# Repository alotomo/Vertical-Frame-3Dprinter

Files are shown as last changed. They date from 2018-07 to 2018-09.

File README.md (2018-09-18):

# Vertical-Frame-3Dprinter
This file is include the 3D CAD, firmware ,Simplify3D fff .
video : https://vimeo.com/286761862

3D CAD data is .IGS file . for solidworks and Fusion360 and more .
Firmware is based marlin-firmware and customized.
.FFF  for Simplify3D

物品リスト is BOM file

FABOOL laser Mini を元に改造したマシンです
https://github.com/smartDIYs
https://www.thingiverse.com/smartDIYs/designs

組み立て参考サイト: https://www.smartdiys.com/manual/fabool-laser-mini/
部品参考サイト: https://www.smartdiys.com/manual/fabool-laser-mini-service-parts/

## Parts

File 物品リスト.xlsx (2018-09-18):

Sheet: 部品リスト
 | マシン本体
 | FABOOL 基本キットから仕様している物 | https://www.smartdiys.com/manual/fabool-laser-mini-service-parts/
 | 品名 | 型番・ファイル名 | 個数 | 備考 | URL
 | プーリー固定用パーツ | FLM_idler pulley plate | 2
 | モーター固定用パーツY軸 | FLM_motor mount plate y-axis | 2
 | モーター固定用パーツX軸 | FLM_motor mount plate x-axis | 1
 | レーザー取り付けプレート | FLM_mini v plate_C | 1 | mini v plate_C
 | ブラケット |  | 4
 | タイミングプーリー |  | 3 | GT2 30歯
 | ステッピングモーター | NEMA17 | 3
 | smooth idler pulleyユニット |  | 3
 | 偏心スペーサー |  | 9
 | ブラケット |  | 4
 | M5 Tナット（先入れ） |  | 16 | 10
 | FABOOL １ｍ拡張キットから仕様している物
 | 20mm角アルミフレーム | V-slot 1170mm | 4
 | 20mm40mmアルミフレーム | V-slot 1210mm | 1
 | アルミフレーム固定用L | FLM_mini v plate_L_2040_1m | 1
 | アルミフレーム固定用R | FLM_mini v plate_R_2040_1m | 1
 | X軸タイミングベルト |  | 1 | GT2 長さ2m以上
 | Y軸タイミングベルト |  | 2 | GT2 長さ2m以上
 | 拡張キット組み立てURL
 | https://www.smartdiys.com/manual/category/fabool-extension-frame/
 | キットに含まれず別途用意する物品
 | 吸盤 | バキュームリフター | 8 | Amazon | http://amzn.asia/d/f4iNQeI (https://e3d-online.com/titan-extruder)
 | 吸盤固定用パーツ | kyuban_0521 V21 | 8 | ３Dプリント品
 | X軸用リミットスイッチ固定用パーツ | Mech_switch_cover | 1 | レーザーカット品
 | Y軸用リミットスイッチ固定用パーツ | Mech_switch_cover_Y | 1 | レーザーカット品
 | ベルトテンション調整機構1 | y_belt_base | 1 | ３Dプリント品
 | ベルトテンション調整機構2 | y_belt_tens | 1 | ３Dプリント品
 | ベアリング | （外形19mm,内径6mm) | 3 | 千石電商など | https://www.sengoku.co.jp/mod/sgk_cart/detail.php?code=EEHD-4JWW
 | ベアリングカバー（厚紙1㎜ or アクリル1mm) | bearing-cover | 3 | レーザーカット品
 | コントロールボードケース１ | MB_Case2 | 1 | ３Dプリント品
 | コントロールボードケース2 | TRIGORILLA_Case_2 | 1 | ３Dプリント品
i | 操作パネルケース1 | LCD_cover | 1 | ３Dプリント品
 | 操作パネルケース2 | LCD_Cover_Bottom | 1 | ３Dプリント品
 | 操作パネルケース3 | LCD_Switch_Bottom | 1 | ３Dプリント品
i | 操作パネルケース固定プレート | LCD_Plate | 1 | レーザーカット品
電子制御部 | コントロールボード | TriGorilla | 1 |  | http://amzn.asia/fg12sFn
 | モータードライバ | A4988 | 1 | (5個セット) | http://amzn.asia/jdB5D4b
 | コントロールパネル | LCD12864 | 1 |  | http://amzn.asia/hCJs8hi
 | 電源用スイッチ |  | 1 | 千石電商 | https://www.sengoku.co.jp/mod/sgk_cart/detail.php?code=EEHD-0GE3
 | 電源用ケーブルAWG16(1.25sq) | 5ｍ程度 |  | オヤイデ電気 | https://oyaide.com/catalog/products/p-2201.html
 | ２．１ｍｍ標準ＤＣプラグ（５Ａ） |  | 1 | 秋月電子 | http://akizukidenshi.com/catalog/g/gC-09311/
 | XT60オスメスコネクタ |  | 1 |  | http://amzn.asia/d/fPNdAga
 | モーター・スイッチケーブル（対数） | MAST-UL2464-24-4P-10 | 1 | 10m | https://jp.misumi-ec.com/vona2/detail/110400411830/?ProductCode=MAST-UL2464-24-8P-10
 | コントロールボード冷却ファン | １２Ｖ３０ｍｍ角 ＤＣファン | 2 | 秋月電子 | http://akizukidenshi.com/catalog/g/gP-02439/
 | JSTコネクタ キット |  |  |  | http://amzn.asia/d/3IZjlXz
 | ジャンプワイヤ |  | 1 |  | http://amzn.asia/d/7e0MaCI
Z機構 ＆ 押出機 | 5mmアクリル | 300mm×500mm | 1
 | 2mmアクリル | 300mm×500mm | 1
 | 小型ステッピングモーター | 28BYJ-48 12Vタイプ | 2 |  | https://ja.aliexpress.com/item/28BYJ-48-Valve-Gear-Stepper-Motor-DC-12V-4-Phase-Step-Motor-Reduction/32554681156.html
 | チューブ継手1.75mm用 | 空気圧継手 PC4-01 | 1 | 1.75mm用 | http://amzn.asia/8W7XnIh
 | フィラメントチューブ1.75mm用 | PTFEチューブ2mm×4mm | 1 | 1.75mm用 | http://amzn.asia/6lfQt3v
 | チューブ継手3.00mm用 | 空気圧継手 PC4-01 | 1 | 3mm用 | http://amzn.asia/aPkcgBb
 | フィラメントチューブ3.00mm用 | PTFEチューブ4mm×6mm | 1 | 3mm用 | http://amzn.asia/8XIWpak
 | 円形インサートナット | 3mm× 5mm× 5mm |  |  | http://amzn.asia/hwDNwGC
 | ベアリング | 8mmベアリング
 | フィラメント押出機 | titan Extruder |  | TYPE１ | https://e3d-online.com/titan-extruder
 |  |  |  |  | http://amzn.asia/ihe9tIm
 |  |  |  |  | https://ja.aliexpress.com/item/BIGTREETECH-Titan-Extruder-Fully-Kits-for-Titan-Extruder-for-1-75mm-Nema-17-Stepper-Motor-V6/32789942768.html
 | 追加パーツ
 | 六角穴付きボルトセット |  |  |  | http://amzn.asia/d/eHFy7Kc
 | 六角穴付組み込みボルトセット |  |  |  | http://amzn.asia/d/cQYwSAI
 | M3/4/5 六角穴付きボルト セット |  |  |  | http://amzn.asia/d/aryfefD
 | M3後入れナット |  | 1 | AliExpress | https://ja.aliexpress.com/store/product/50-m3-m4-m5-t-2020/3108017_32834673316.html
 | M4後入れナット |  | 1 | AliExpress | https://ja.aliexpress.com/store/product/50-m3-m4-m5-t-2020/3108017_32834673316.html
 | M5後入れナット |  | 1 | AliExpress | https://ja.aliexpress.com/store/product/50-m3-m4-m5-t-2020/3108017_32834673316.html
 | マシン剛性強化パーツ
 | 押出厚型ブラケット | HBLTS5 |  | MISUMI | https://jp.misumi-ec.com/vona2/detail/110300438050/?HissuCode=HBLTS5
 | 検討・改良用パーツ
 | 3フィラメント混合ノズル | Diamond Extruder |  | 今回未使用 | https://ja.aliexpress.com/item/Diamond-3D-Printer-Extruder-Hotend-3D-V6-heatsink-3-IN-1-OUT-Multi-Nozzle-KOSSEL-full/32779018878.html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

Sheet: Fabool公式
参考URL
https://www.smartdiys.com/manual/fabool-laser-mini-service-parts/
FABOOL Laser Mini マニュアル
保守部品
保守部品 価格表
品名 | 販売単位 | 価格(税込) | 備考
1.6Wレーザーユニット（レーザー基板付属） | 1 | 16,740円
3.5Wレーザーユニット（レーザー基板付属） | 1 | 36,504円
コントロール基板 | 1 | 7,980円
V-slot 450mm | 1 | 2,700円
V-slot 410mm | 1 | 2,484円
ブラケット | 4 | 1,728円
タイミングプーリー | 1 | 1,274円 | GT2 30歯
X軸タイミングベルト | 1 | 850円 | GT2 長さ1060m
Y軸タイミングベルト | 1 | 800円 | GT2 長さ1000m
光学ステージ | 1 | 1,760円
光学キャリア | 1 | 1,760円
PCBケース | 1 | 2,700円
mini v plate_C | 1 | 3,240円 | 組立済
mini v plate_L | 1 | 3,110円 | 組立済
mini v plate_R | 1 | 3,780円 | 組立済
idler pulley plate | 1 | 1,620円 | 組立済
ACアダプタ | 1 | 2,160円
ACケーブル | 1 | 518円
USBケーブル | 1 | 864円
ステッピングモーター | 1 | 1,922円
DCファン | 1 | 540円 | PCBケース用
PCBケーブル | 1 | 518円
Laserケーブル | 1 | 1,382円
X-Axisケーブル | 1 | 950円
Y-Axis-Rケーブル | 1 | 518円
Y-Axis-Lケーブル | 1 | 950円
Foot Switchケーブル | 1 | 842円
保護メガネ | 1 | 2,462円
高さ調整用アクリル | 1 | 216円
結束バンド固定具 | 6 | 518円
結束バンド | 25 | 410円
mini v wheelユニット | 1 | 1,058円
smooth idler pulleyユニット | 1 | 1,058円
偏心スペーサー | 3 | 907円
motor mount plate x-axis | 1 | 1,382円
motor mount plate y-axis | 1 | 1,620円
M3×6 六角穴付き皿ボルト | 5 | 410円 | PCBケース用ネジ
M6×8 六角穴付きボルト | 3 | 410円
M5×8 低頭ボルト | 5 | 518円
M5×6 低頭ボルト | 5 | 518円
M4×6 六角穴付きボルト | 1 | 130円
M3×10 六角穴付きボルト | 5 | 410円
M3×6 六角穴付きボルト | 5 | 410円
M3×4 六角穴付きボルト | 5 | 410円
M2×10 六角穴付きボルト | 5 | 410円
M5 Tナット | 5 | 410円
M3後入れナット | 3 | 410円

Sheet: Sheet1
部品データ
レーザーカッター | メーカー | 個数 | 備考 |  | オプション | 代用可
FABOOL Laser Mini 1.6W | SmartDIYs | 1 |  | https://shop.smartdiys.com/products/detail.php?product_id=773
拡張フレームセット(加工エリア1m×1m) | SmartDIYs | 1 |  | https://shop.smartdiys.com/products/detail.php?product_id=779
Z機構改造パーツ
部品・材料 | 部品名・型番 | 個数 | 備考 | 購入参考URL
5mmアクリル
2mmアクリル
小型ステッピングモーター | 28BYJ-48 12Vタイプ |  |  | https://ja.aliexpress.com/item/28BYJ-48-Valve-Gear-Stepper-Motor-DC-12V-4-Phase-Step-Motor-Reduction/32554681156.html
チューブ継手1.75mm用 | 空気圧継手 PC4-01 | 1 | 1.75mm用 | http://amzn.asia/8W7XnIh
フィラメントチューブ1.75mm用 | PTFEチューブ2mm×4mm | 1 | 1.75mm用 | http://amzn.asia/6lfQt3v
チューブ継手3.00mm用 | 空気圧継手 PC4-01 | 1 | 3mm用 | http://amzn.asia/aPkcgBb
フィラメントチューブ3.00mm用 | PTFEチューブ4mm×6mm | 1 | 3mm用 | http://amzn.asia/8XIWpak
円形インサートナット | 3mm× 5mm× 5mm |  |  | http://amzn.asia/hwDNwGC
ベアリング | 8mmベアリング
フィラメント押出機 | titan Extruder |  | TYPE１ | https://e3d-online.com/titan-extruder
 |  |  |  | http://amzn.asia/ihe9tIm
 |  |  |  | https://ja.aliexpress.com/item/BIGTREETECH-Titan-Extruder-Fully-Kits-for-Titan-Extruder-for-1-75mm-Nema-17-Stepper-Motor-V6/32789942768.html
電子制御部
コントロールボード | TriGorilla | 1 |  | http://amzn.asia/fg12sFn
モータードライバ | A4988 | 1 | (5個セット) | http://amzn.asia/jdB5D4b
コントロールパネル | LCD12864 | 1 |  | http://amzn.asia/hCJs8hi
電源用スイッチ |  | 1 | 千石電商 | https://www.sengoku.co.jp/mod/sgk_cart/detail.php?code=EEHD-0GE3 |  | 〇
電源用ケーブルAWG16(1.25sq) | 5ｍ程度 |  | オヤイデ電気 | https://oyaide.com/catalog/products/p-2201.html |  | 〇
２．１ｍｍ標準ＤＣプラグ（５Ａ） |  | 1 | 秋月電子 | http://akizukidenshi.com/catalog/g/gC-09311/ | オプション・電源端子を別途使う場合のみ | 〇
XT60オスメスコネクタ |  | 1 |  | http://amzn.asia/d/fPNdAga |  | 〇
コントロールボード冷却ファン | １２Ｖ３０ｍｍ角 ＤＣファン | 2 | 秋月電子 | http://akizukidenshi.com/catalog/g/gP-02439/ |  | 〇
ジャンプワイヤ |  | 1 |  | http://amzn.asia/d/7e0MaCI |  | 〇
追加パーツ
JSTコネクタ キット |  |  |  | http://amzn.asia/d/3IZjlXz
六角穴付きボルトセット |  |  |  | http://amzn.asia/d/eHFy7Kc
六角穴付組み込みボルトセット |  |  |  | http://amzn.asia/d/cQYwSAI
M3/4/5 六角穴付きボルト セット |  |  |  | http://amzn.asia/d/aryfefD
M3後入れナット |  | 1 | AliExpress | https://ja.aliexpress.com/store/product/50-m3-m4-m5-t-2020/3108017_32834673316.html
M4後入れナット |  | 1 | AliExpress | https://ja.aliexpress.com/store/product/50-m3-m4-m5-t-2020/3108017_32834673316.html
M5後入れナット |  | 1 | AliExpress | https://ja.aliexpress.com/store/product/50-m3-m4-m5-t-2020/3108017_32834673316.html
マシン剛性強化パーツ
押出厚型ブラケット | HBLTS5 |  | MISUMI | https://jp.misumi-ec.com/vona2/detail/110300438050/?HissuCode=HBLTS5
検討・改良用パーツ
3フィラメント混合ノズル | Diamond Extruder |  | 今回未使用 | https://ja.aliexpress.com/item/Diamond-3D-Printer-Extruder-Hotend-3D-V6-heatsink-3-IN-1-OUT-Multi-Nozzle-KOSSEL-full/32779018878.html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

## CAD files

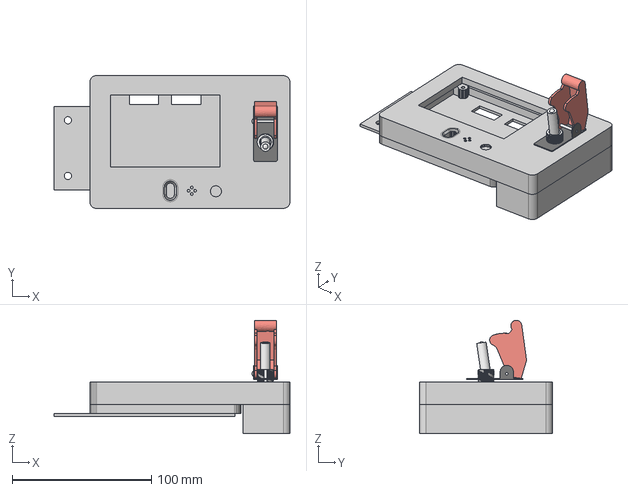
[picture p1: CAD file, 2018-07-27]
controller_case.iges
169.6 x 95.4 x 81.5 mm

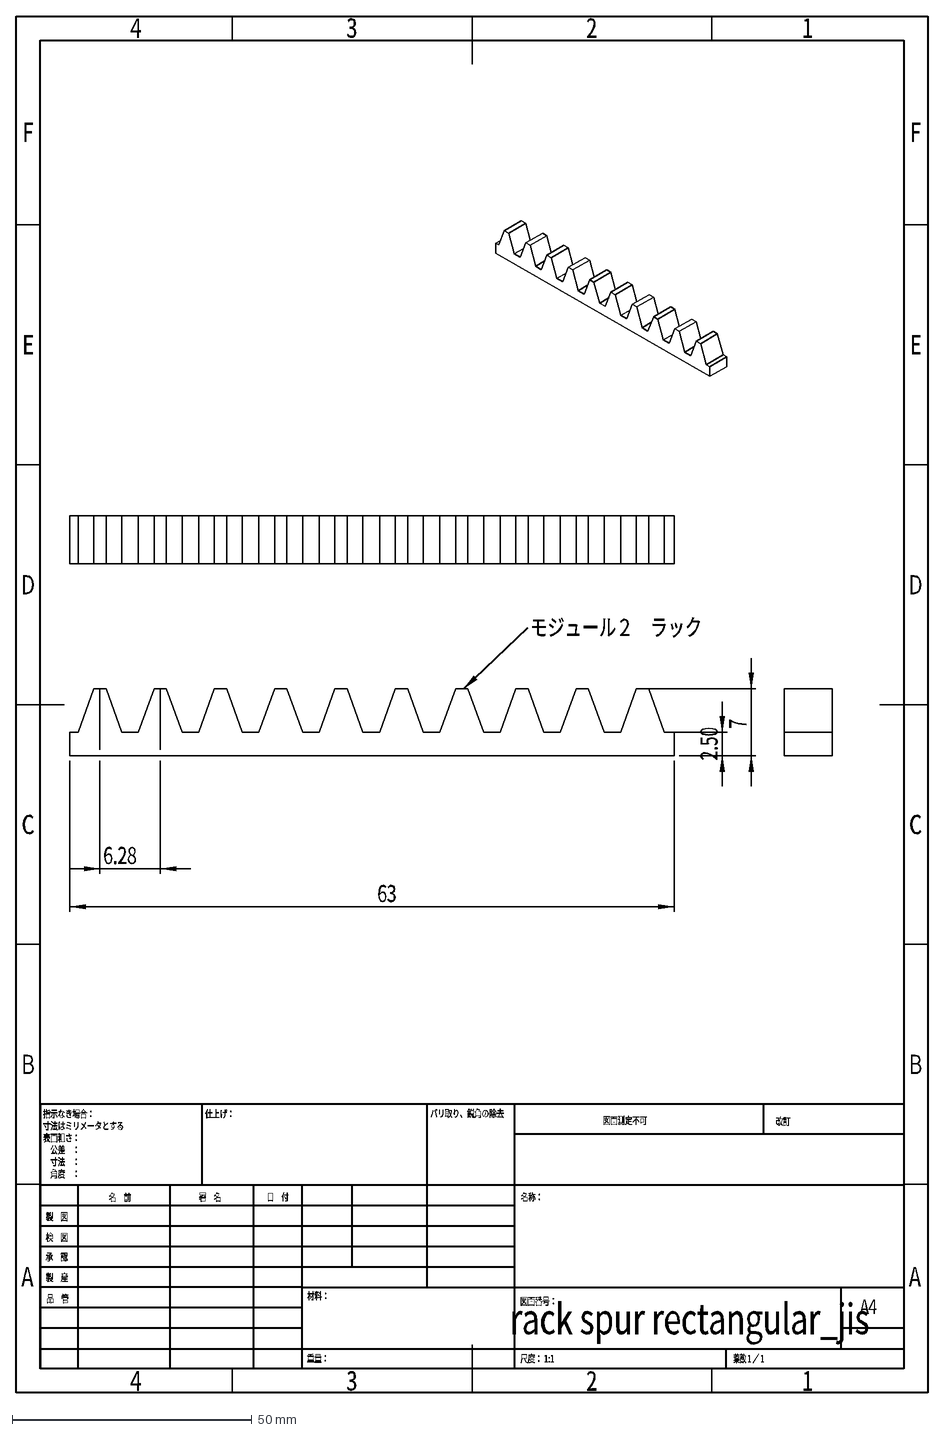
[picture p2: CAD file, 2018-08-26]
図面/rack spur rectangular_jis.DXF
A
B
C
D
E
F
4
3
2
1
rack spur rectangular_jis
重量：
A4
葉数 1 ／ 1
尺度： 1:1
図面番号：
名称：
改訂
図面測定不可
材料：
日 付
署 名
名 前
バリ取り、鋭角の除去
仕上げ：
指示なき場合：
寸法はミリメータとする
表面粗さ：
公差 ：
寸法 ：
角度 ：
品 管
製 産
承 認
検 図
製 図
6.28
2.50
7
63
モジュール２ ラック

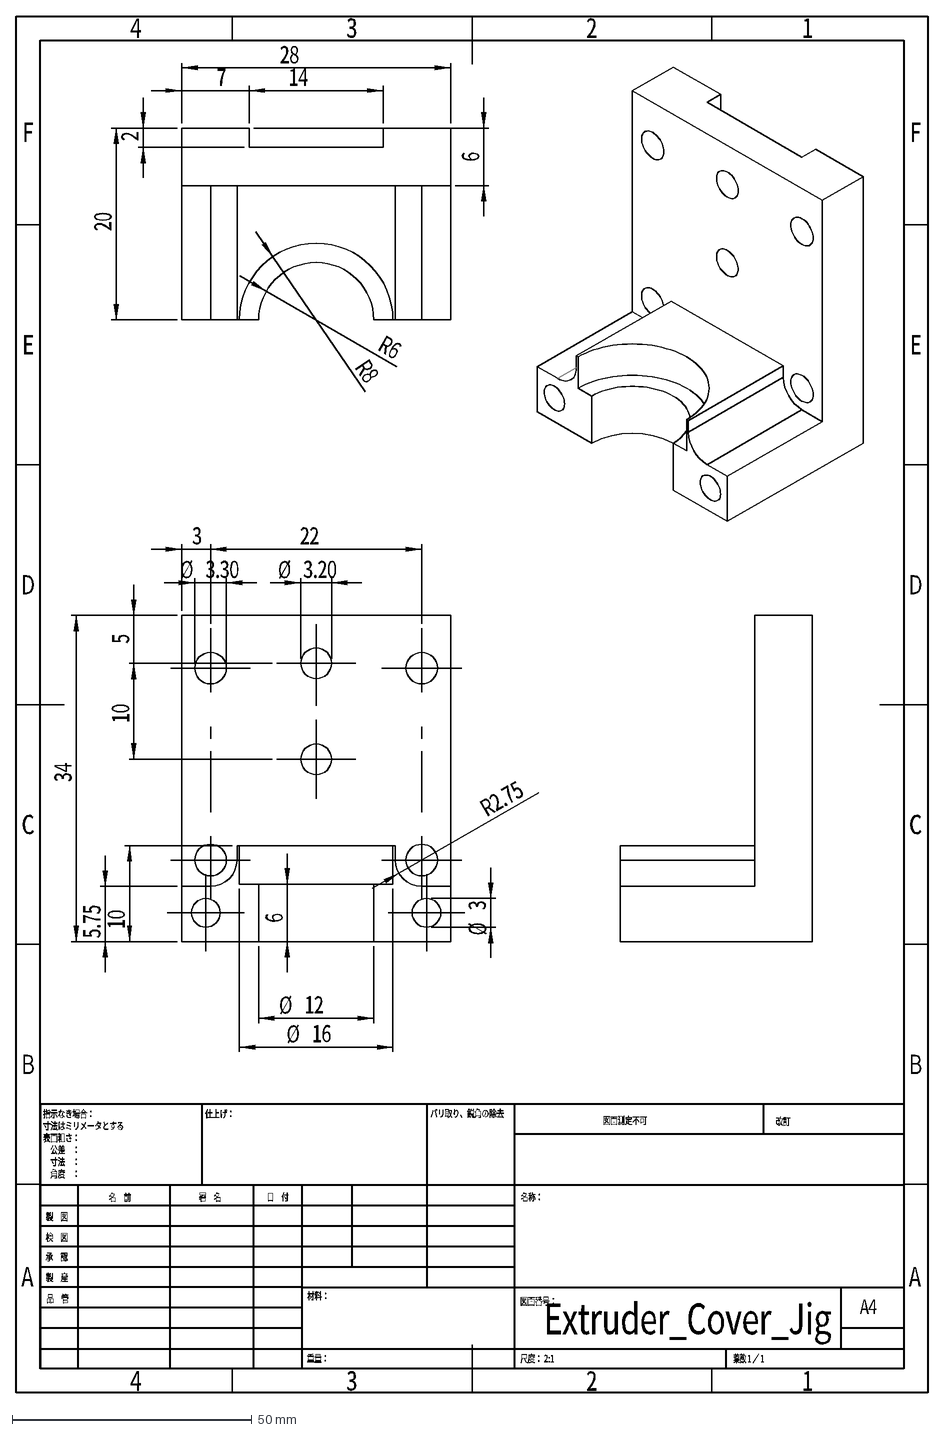
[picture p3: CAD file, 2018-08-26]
図面/Extruder_Cover_Jig.DXF
A
B
C
D
E
F
4
3
2
1
Extruder_Cover_Jig
重量：
A4
葉数 1 ／ 1
尺度： 2:1
図面番号：
名称：
改訂
図面測定不可
材料：
日 付
署 名
名 前
バリ取り、鋭角の除去
仕上げ：
指示なき場合：
寸法はミリメータとする
表面粗さ：
公差 ：
寸法 ：
角度 ：
品 管
製 産
承 認
検 図
製 図
34
5.75
10
Ø
12
16
R2.75
22
5
3.30
3.20
6
20
7
28
14
R6
R8

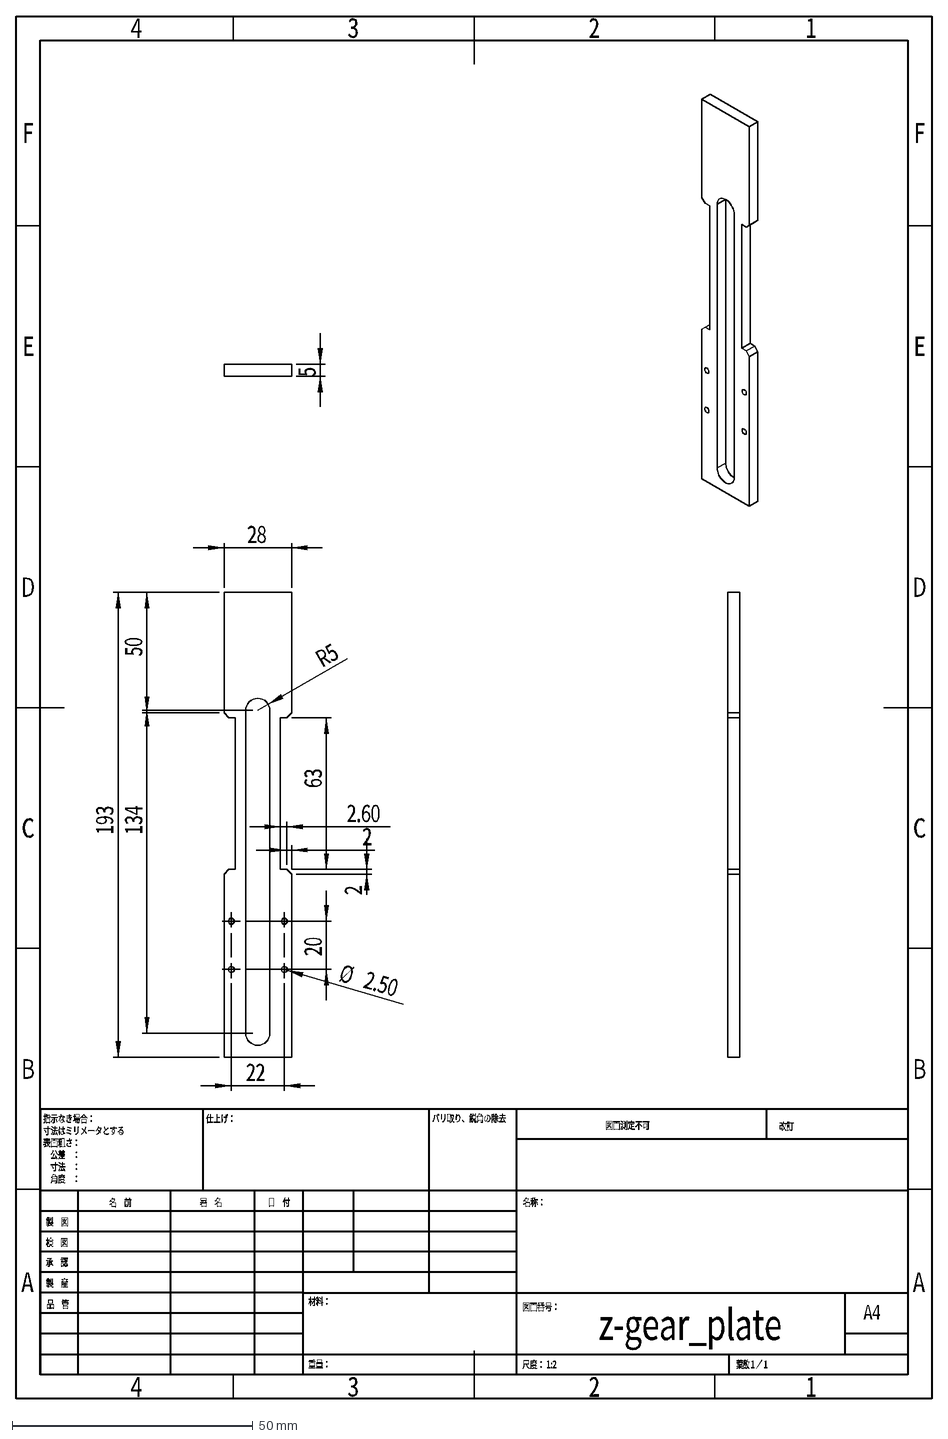
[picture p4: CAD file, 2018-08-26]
図面/z-gear_plate.DXF
A
B
C
D
E
F
4
3
2
1
z-gear_plate
重量：
A4
葉数 1 ／ 1
尺度： 1:2
図面番号：
名称：
改訂
図面測定不可
材料：
日 付
署 名
名 前
バリ取り、鋭角の除去
仕上げ：
指示なき場合：
寸法はミリメータとする
表面粗さ：
公差 ：
寸法 ：
角度 ：
品 管
製 産
承 認
検 図
製 図
193
28
50
134
R5
20
22
63
2.60
Ø
2.50
5

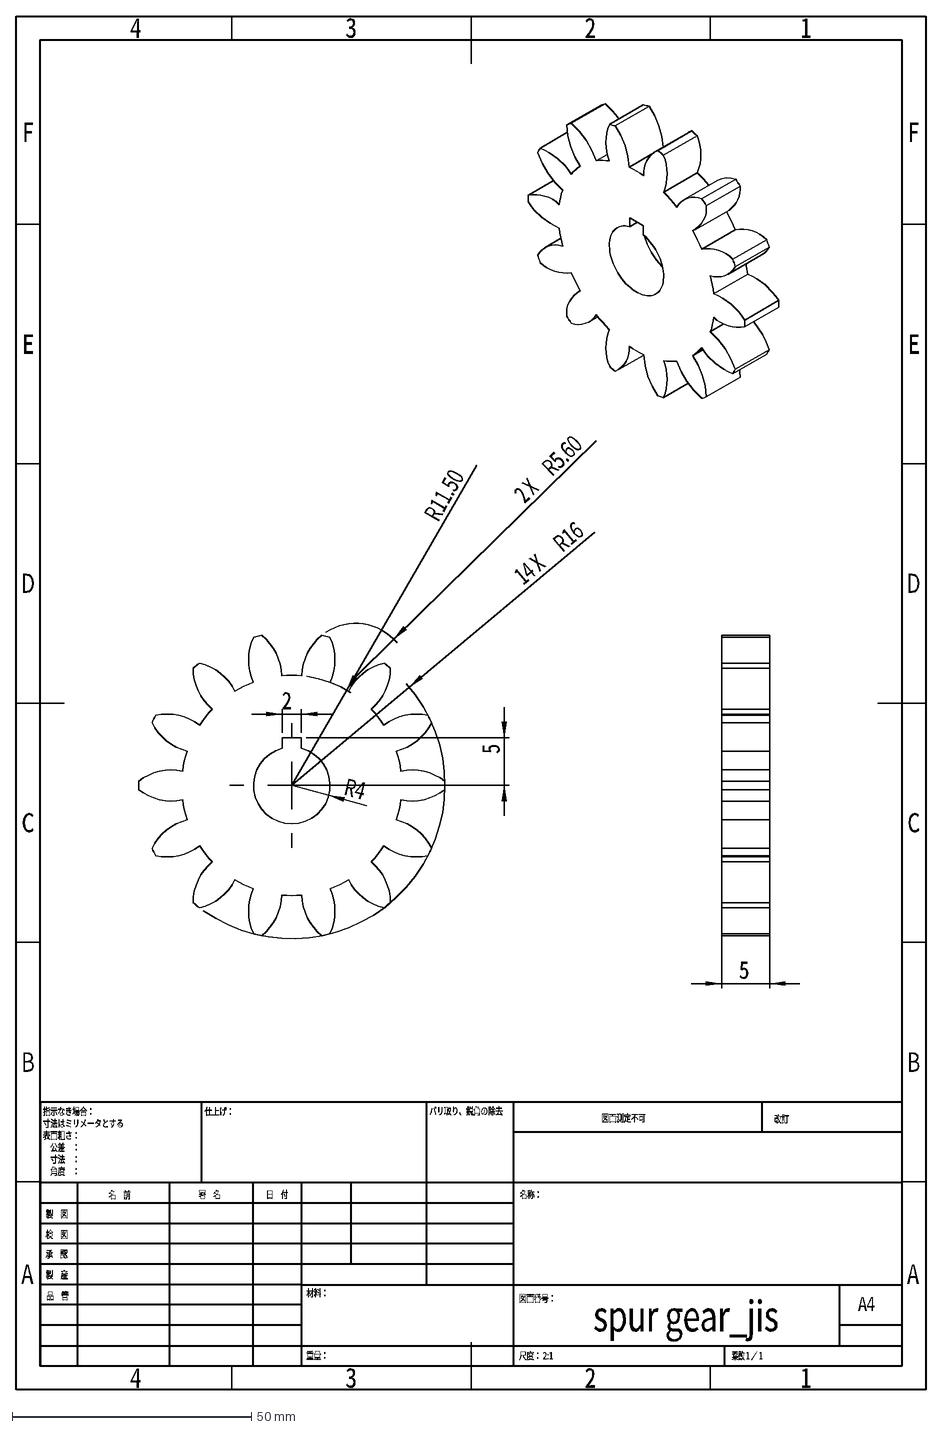
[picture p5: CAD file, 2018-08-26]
図面/spur gear_jis.DXF
A
B
C
D
E
F
4
3
2
1
spur gear_jis
重量：
A4
葉数 1 ／ 1
尺度： 2:1
図面番号：
名称：
改訂
図面測定不可
材料：
日 付
署 名
名 前
バリ取り、鋭角の除去
仕上げ：
指示なき場合：
寸法はミリメータとする
表面粗さ：
公差 ：
寸法 ：
角度 ：
品 管
製 産
承 認
検 図
製 図
R4
5
14 X
R16
2 X
R5.60
R11.50

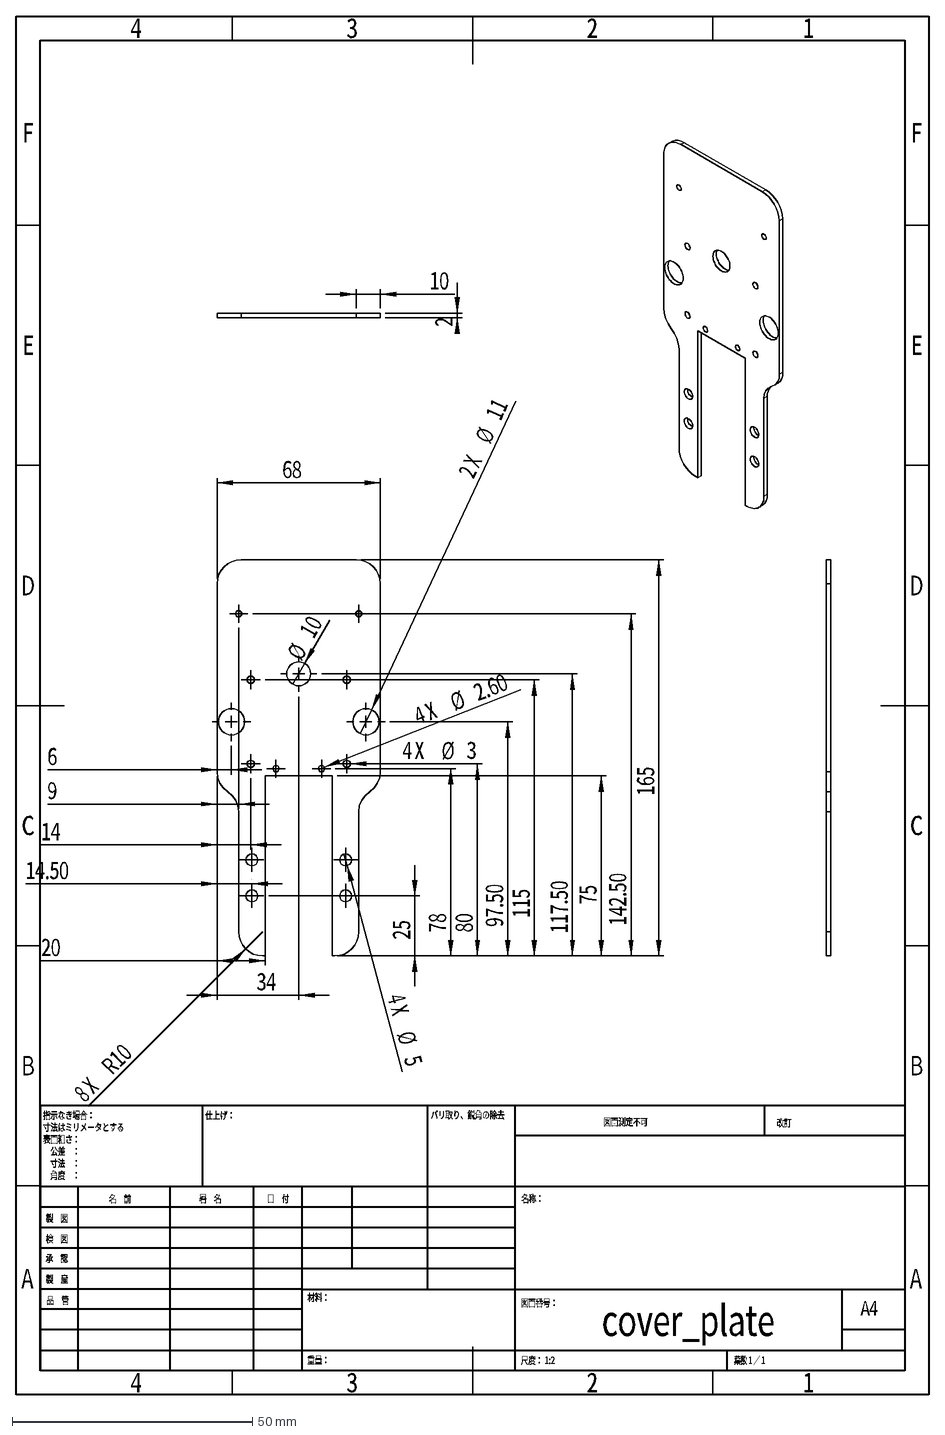
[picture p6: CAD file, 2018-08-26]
図面/cover_plate.DXF
A
B
C
D
E
F
4
3
2
1
cover_plate
重量：
A4
葉数 1 ／ 1
尺度： 1:2
図面番号：
名称：
改訂
図面測定不可
材料：
日 付
署 名
名 前
バリ取り、鋭角の除去
仕上げ：
指示なき場合：
寸法はミリメータとする
表面粗さ：
公差 ：
寸法 ：
角度 ：
品 管
製 産
承 認
検 図
製 図
6
9
14
14.50
20
34
25
78
80
97.50
115
117.50
75
142.50
Ø
10
4 X
2.60
2 X
11
5
8 X
R10
165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

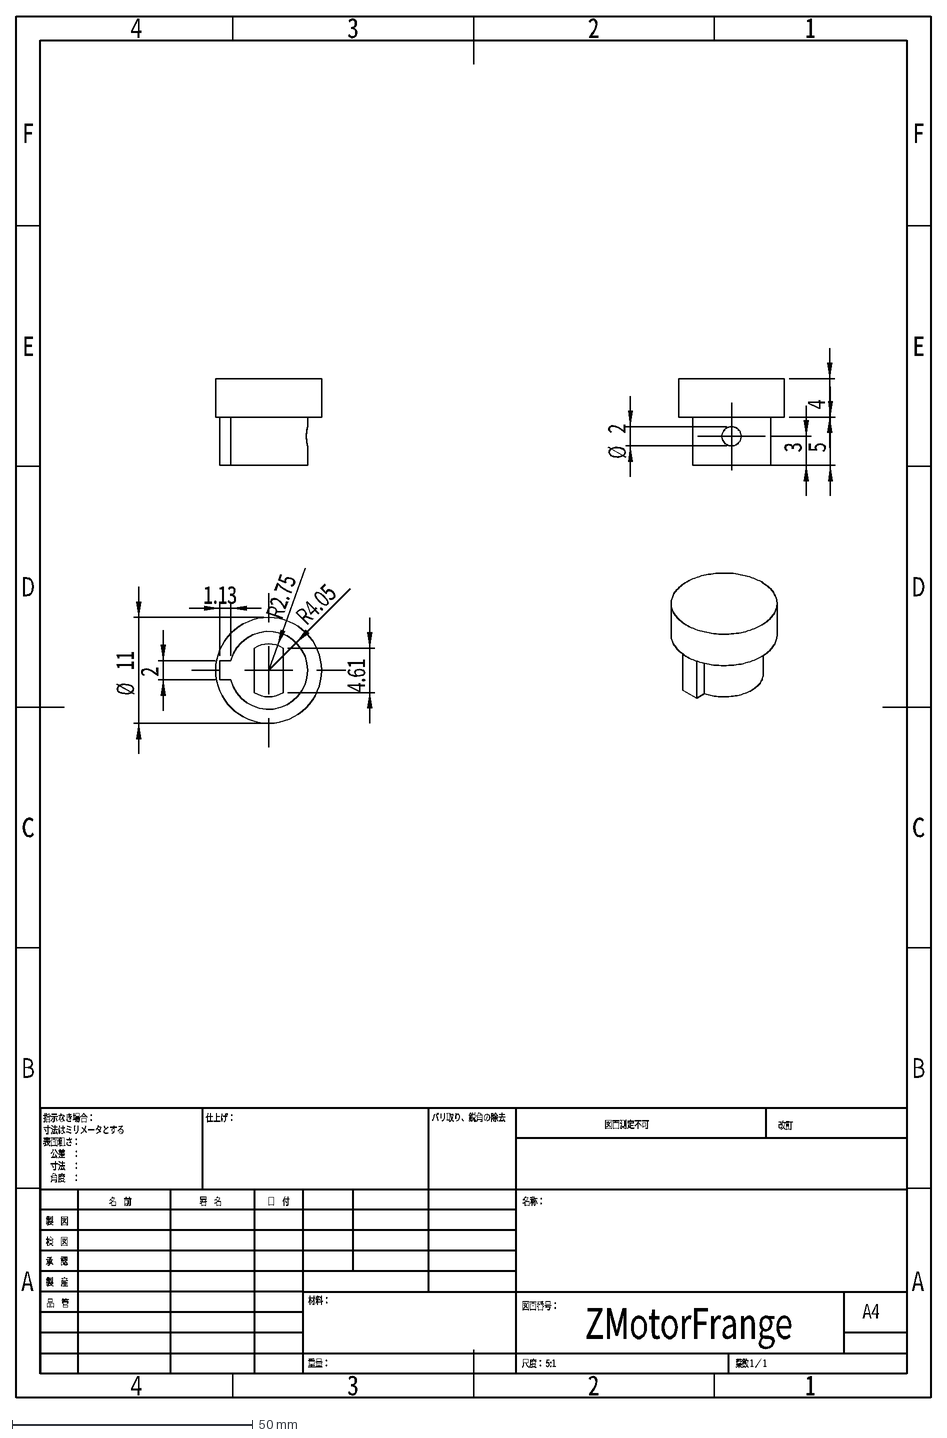
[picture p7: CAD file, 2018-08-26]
図面/ZMotorFrange.DXF
A
B
C
D
E
F
4
3
2
1
ZMotorFrange
重量：
A4
葉数 1 ／ 1
尺度： 5:1
図面番号：
名称：
改訂
図面測定不可
材料：
日 付
署 名
名 前
バリ取り、鋭角の除去
仕上げ：
指示なき場合：
寸法はミリメータとする
表面粗さ：
公差 ：
寸法 ：
角度 ：
品 管
製 産
承 認
検 図
製 図
Ø
11
R4.05
4.61
R2.75
1.13
5

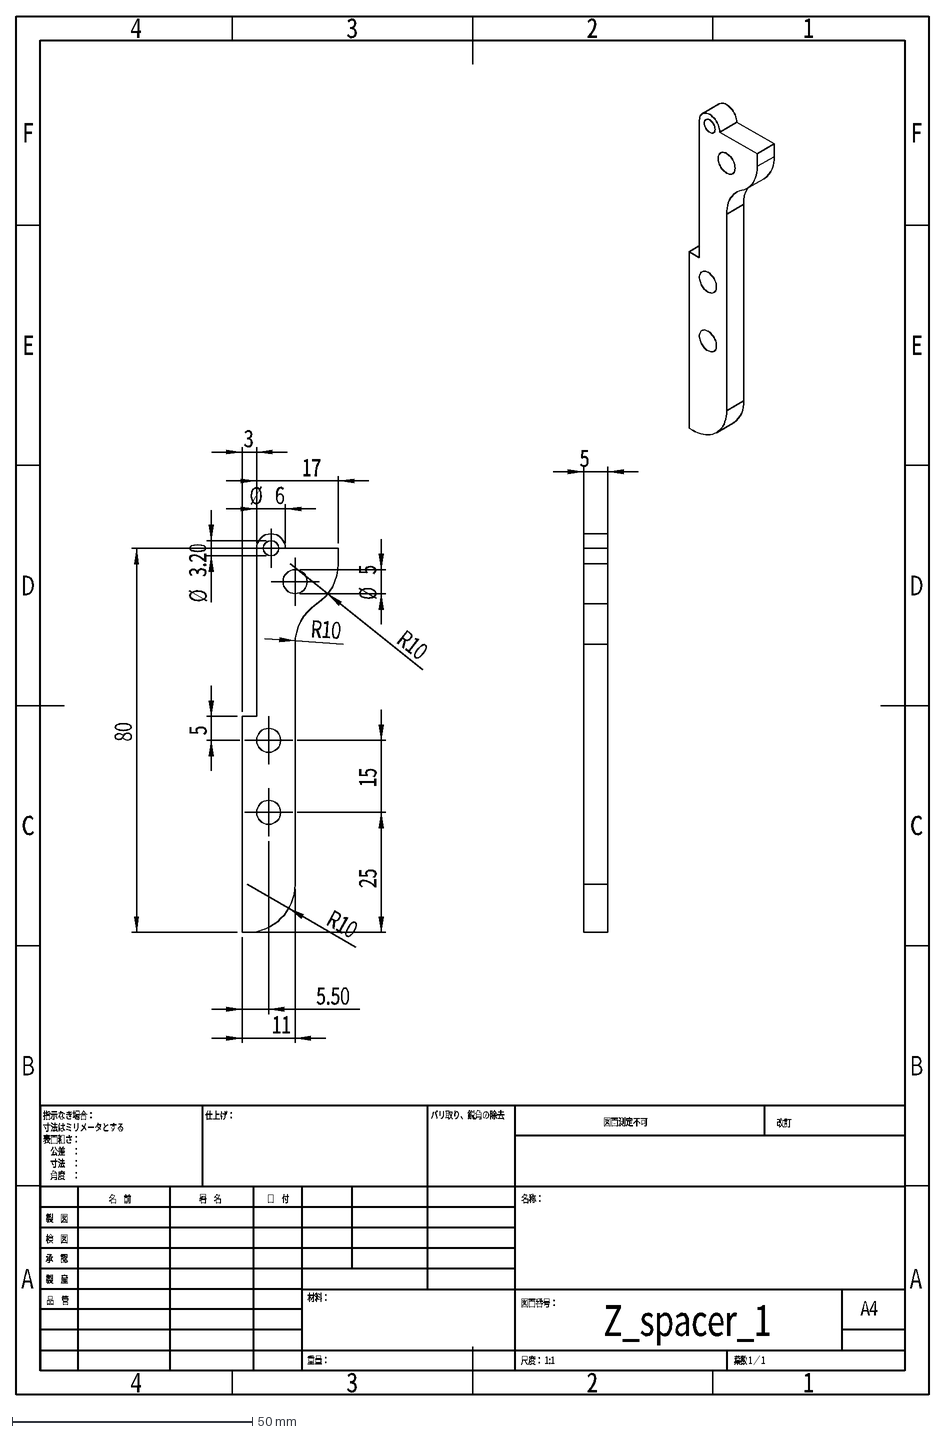
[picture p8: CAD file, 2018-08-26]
図面/Z_spacer_1.DXF
A
B
C
D
E
F
4
3
2
1
Z_spacer_1
重量：
A4
葉数 1 ／ 1
尺度： 1:1
図面番号：
名称：
改訂
図面測定不可
材料：
日 付
署 名
名 前
バリ取り、鋭角の除去
仕上げ：
指示なき場合：
寸法はミリメータとする
表面粗さ：
公差 ：
寸法 ：
角度 ：
品 管
製 産
承 認
検 図
製 図
80
Ø
6
17
3.20
5
11
R10
15
5.50
25

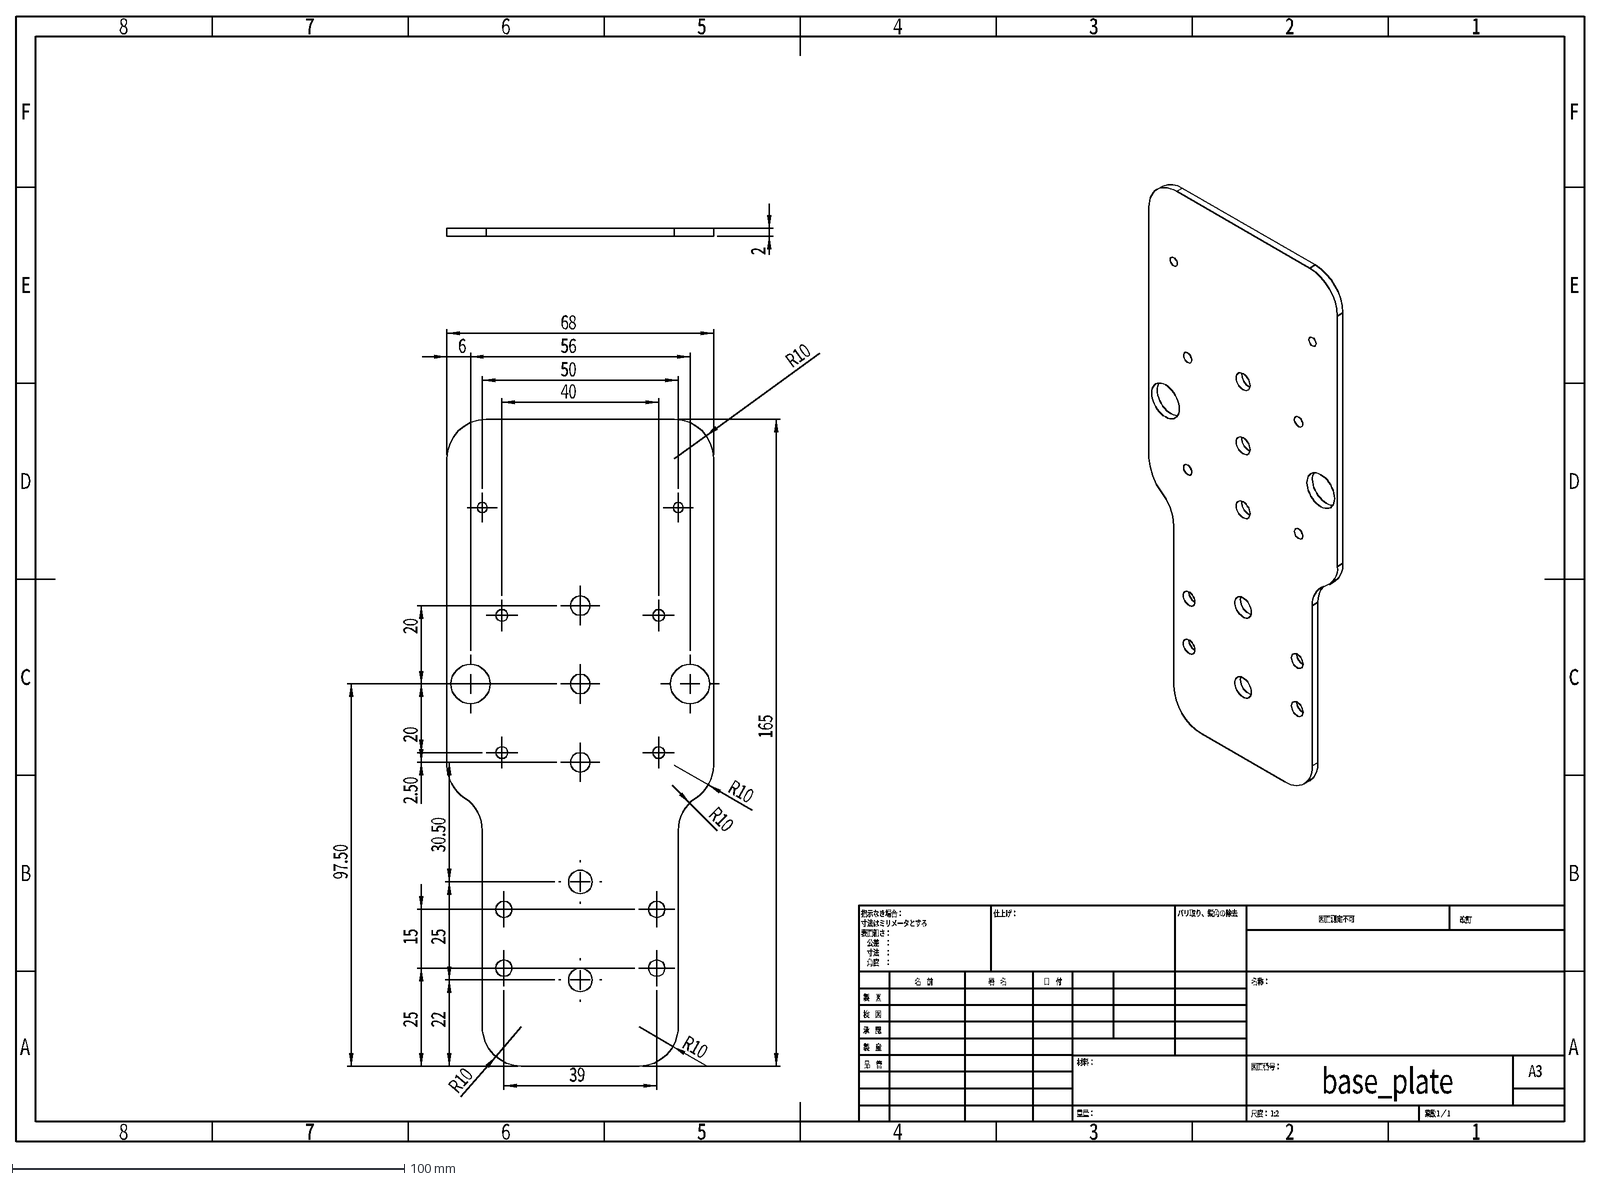
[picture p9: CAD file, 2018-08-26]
図面/base_plate.DXF
A
B
C
D
E
F
8
7
6
5
4
3
2
1
base_plate
重量：
A3
葉数 1 ／ 1
尺度： 1:2
図面番号：
名称：
改訂
図面測定不可
材料：
日 付
署 名
名 前
バリ取り、鋭角の除去
仕上げ：
指示なき場合：
寸法はミリメータとする
表面粗さ：
公差 ：
寸法 ：
角度 ：
品 管
製 産
承 認
検 図
製 図
165
68
R10
56
50
40
20
39
15
97.50
22
25
30.50
2.50

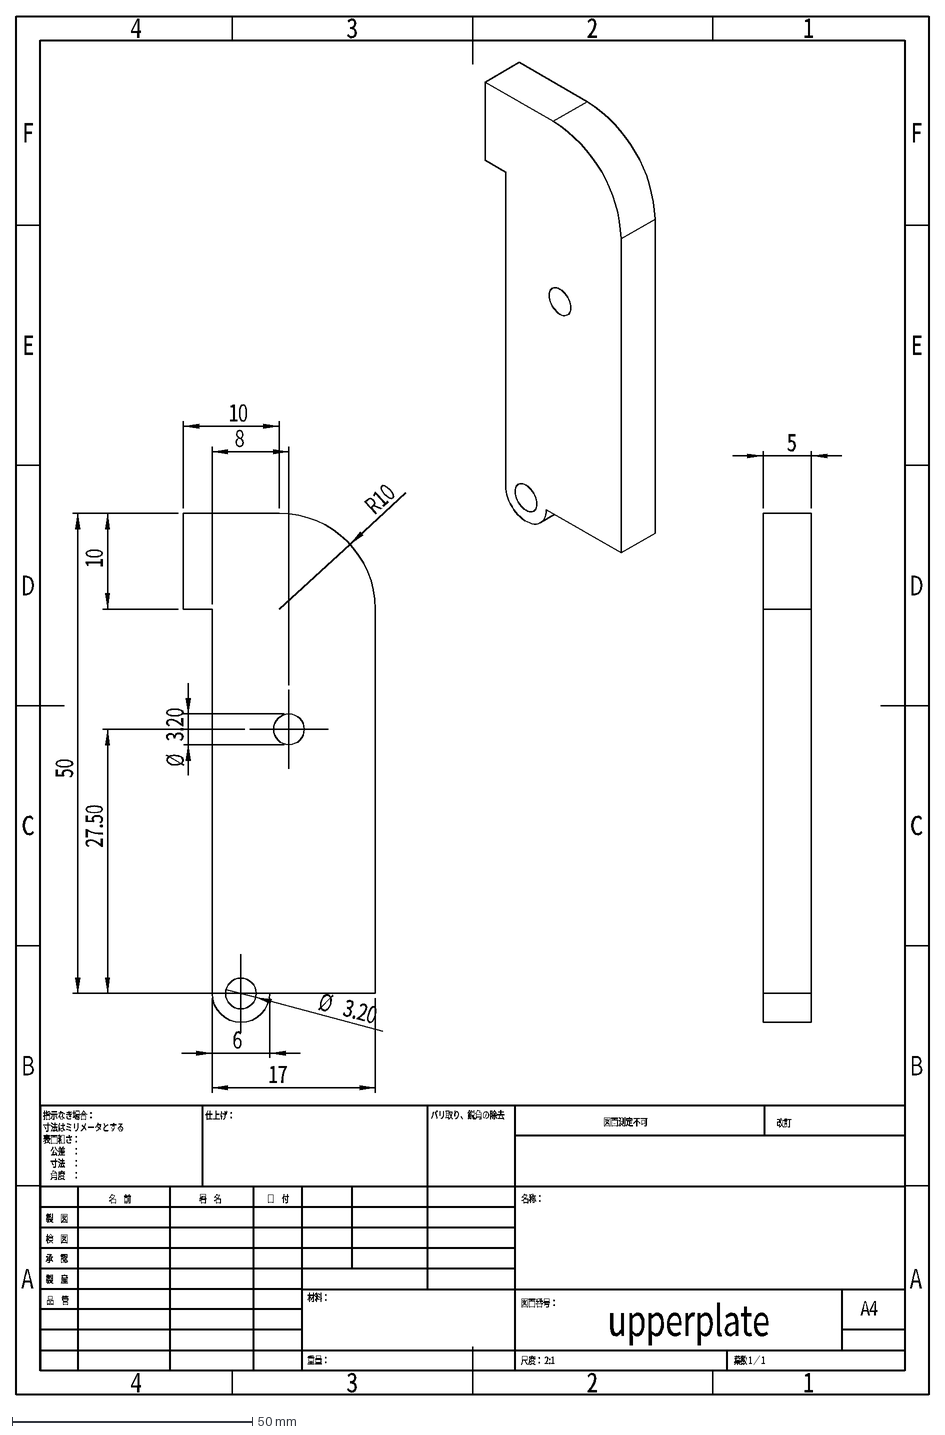
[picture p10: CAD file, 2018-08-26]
図面/upperplate.DXF
A
B
C
D
E
F
4
3
2
1
upperplate
重量：
A4
葉数 1 ／ 1
尺度： 2:1
図面番号：
名称：
改訂
図面測定不可
材料：
日 付
署 名
名 前
バリ取り、鋭角の除去
仕上げ：
指示なき場合：
寸法はミリメータとする
表面粗さ：
公差 ：
寸法 ：
角度 ：
品 管
製 産
承 認
検 図
製 図
10
50
Ø
3.20
6
17
R10
27.50
8
5

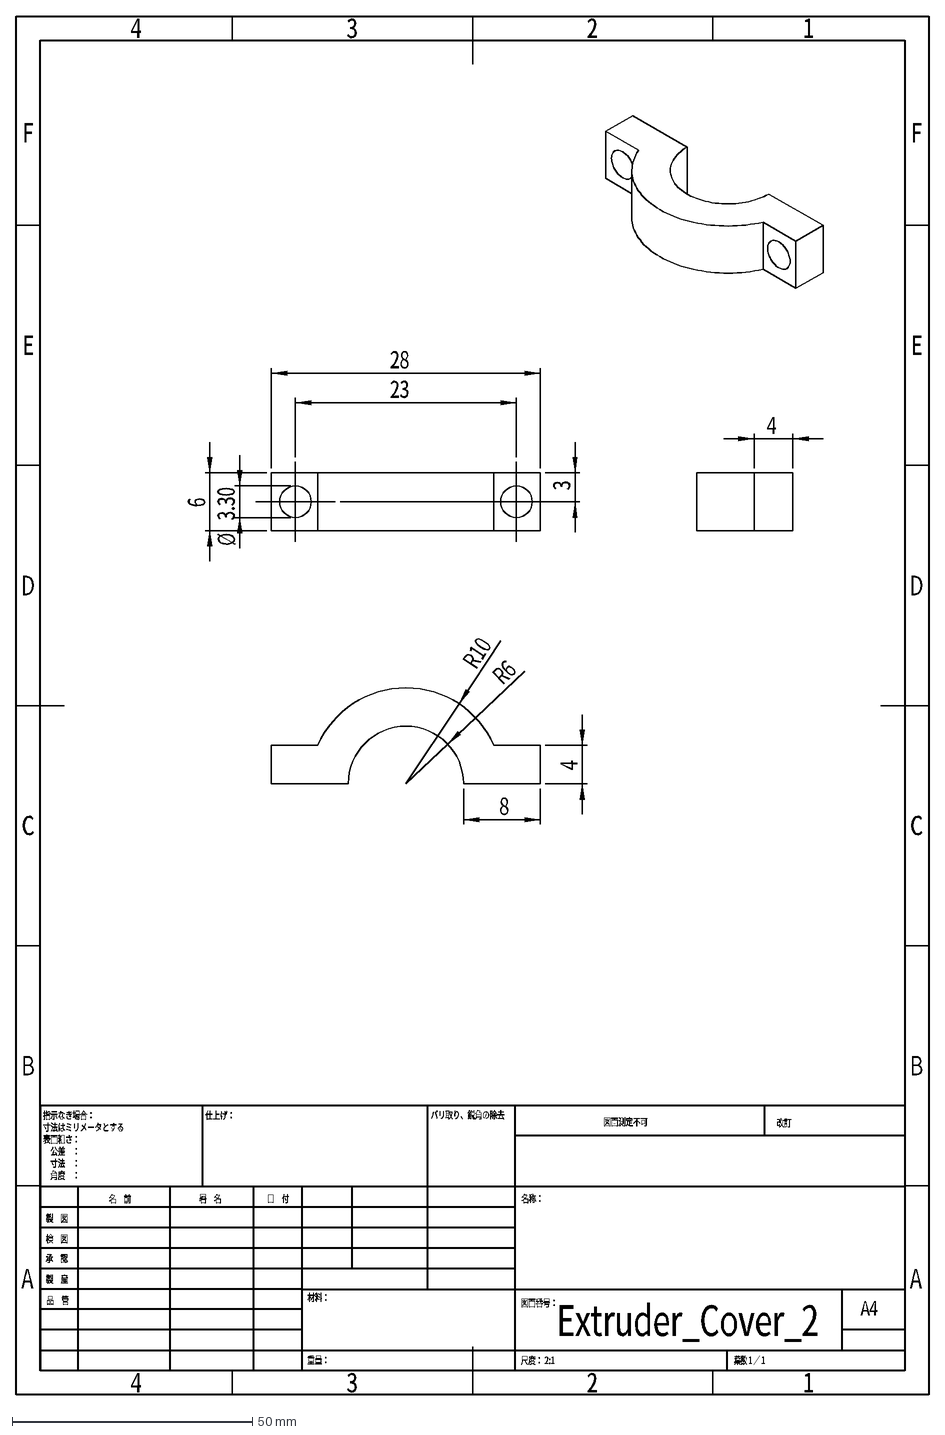
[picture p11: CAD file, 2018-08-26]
図面/Extruder_Cover_2.DXF
A
B
C
D
E
F
4
3
2
1
Extruder_Cover_2
重量：
A4
葉数 1 ／ 1
尺度： 2:1
図面番号：
名称：
改訂
図面測定不可
材料：
日 付
署 名
名 前
バリ取り、鋭角の除去
仕上げ：
指示なき場合：
寸法はミリメータとする
表面粗さ：
公差 ：
寸法 ：
角度 ：
品 管
製 産
承 認
検 図
製 図
28
6
Ø
3.30
23
R10
R6
8

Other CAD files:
図面/Extruder_Cover_2.SLDDRW
図面/Extruder_Cover_Jig.SLDDRW
図面/ZMotorFrange.SLDDRW
図面/Z_spacer_1.SLDDRW
図面/base_plate.SLDDRW
図面/cover_plate.SLDDRW
図面/rack spur rectangular_jis.SLDDRW
図面/spur gear_jis.SLDDRW
図面/upperplate.SLDDRW
図面/z-gear_plate.SLDDRW

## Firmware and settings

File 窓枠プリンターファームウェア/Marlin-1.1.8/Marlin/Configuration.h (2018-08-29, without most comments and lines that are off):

#define CONFIGURATION_H
#define CONFIGURATION_H_VERSION 010107
#define STRING_CONFIG_H_AUTHOR "(none, default config)" // Who made the changes.
#define SHOW_BOOTSCREEN
#define STRING_SPLASH_LINE1 SHORT_BUILD_VERSION // will be shown during bootup in line 1
#define STRING_SPLASH_LINE2 WEBSITE_URL         // will be shown during bootup in line 2
#define SERIAL_PORT 0
#define BAUDRATE 115200
  #define MOTHERBOARD 44
#define CUSTOM_MACHINE_NAME "MadowaKun"
#define EXTRUDERS 1
#define DEFAULT_NOMINAL_FILAMENT_DIA 1.75
#define POWER_SUPPLY 0
#define TEMP_SENSOR_0 1 //1 999
#define TEMP_SENSOR_1 0
#define TEMP_SENSOR_2 0
#define TEMP_SENSOR_BED 0
#define DUMMY_THERMISTOR_998_VALUE 25
#define DUMMY_THERMISTOR_999_VALUE 190
#define MAX_REDUNDANT_TEMP_SENSOR_DIFF 10
#define TEMP_RESIDENCY_TIME 10  // (seconds)
#define TEMP_HYSTERESIS 3       // (degC) range of +/- temperatures considered "close" to the target one
#define TEMP_WINDOW     1       // (degC) Window around target to start the residency timer x degC early.
#define TEMP_BED_RESIDENCY_TIME 10  // (seconds)
#define TEMP_BED_HYSTERESIS 3       // (degC) range of +/- temperatures considered "close" to the target one
#define TEMP_BED_WINDOW     1       // (degC) Window around target to start the residency timer x degC early.
#define HEATER_0_MINTEMP 5
#define HEATER_1_MINTEMP 5
#define HEATER_2_MINTEMP 5
#define HEATER_3_MINTEMP 5
#define HEATER_4_MINTEMP 5
#define BED_MINTEMP 5
#define HEATER_0_MAXTEMP 275
#define HEATER_1_MAXTEMP 275
#define HEATER_2_MAXTEMP 275
#define HEATER_3_MAXTEMP 275
#define HEATER_4_MAXTEMP 275
#define BED_MAXTEMP 150
#define PIDTEMP
#define BANG_MAX 255     // Limits current to nozzle while in bang-bang mode; 255=full current
#define PID_MAX BANG_MAX // Limits current to nozzle while PID is active (see PID_FUNCTIONAL_RANGE below); 255=full current
#define PID_K1 0.95      // Smoothing factor within the PID
  #define PID_FUNCTIONAL_RANGE 10 // If the temperature difference between the target temperature and the actual temperature
  #define  DEFAULT_Kp 22.2
  #define  DEFAULT_Ki 1.08
  #define  DEFAULT_Kd 114
#define MAX_BED_POWER 255 // limits duty cycle to bed; 255=full current
#define PREVENT_COLD_EXTRUSION
#define EXTRUDE_MINTEMP 170
#define PREVENT_LENGTHY_EXTRUDE
#define EXTRUDE_MAXLENGTH 200
#define THERMAL_PROTECTION_HOTENDS // Enable thermal protection for all extruders
#define THERMAL_PROTECTION_BED     // Enable thermal protection for the heated bed
#define USE_XMIN_PLUG
#define USE_YMIN_PLUG
#define USE_ZMIN_PLUG
#define USE_XMAX_PLUG
#define USE_YMAX_PLUG
#define USE_ZMAX_PLUG
#define ENDSTOPPULLUPS // Comment this out (using // at the start of the line) to disable the endstop pullup resistors
#define X_MIN_ENDSTOP_INVERTING true // set to true to invert the logic of the endstop.
#define Y_MIN_ENDSTOP_INVERTING true // set to true to invert the logic of the endstop.
#define Z_MIN_ENDSTOP_INVERTING true // set to true to invert the logic of the endstop.
#define X_MAX_ENDSTOP_INVERTING true // set to true to invert the logic of the endstop.
#define Y_MAX_ENDSTOP_INVERTING true // set to true to invert the logic of the endstop.
#define Z_MAX_ENDSTOP_INVERTING true // set to true to invert the logic of the endstop.
#define Z_MIN_PROBE_ENDSTOP_INVERTING false // set to true to invert the logic of the probe.
#define DEFAULT_AXIS_STEPS_PER_UNIT   { 53.33, 53.33, 400, 418.5 } //53.33 655.36
#define DEFAULT_MAX_FEEDRATE          { 3000, 3000, 200, 180/60 }//90/60
#define DEFAULT_MAX_ACCELERATION      { 2000, 2000, 200, 1000 }
#define DEFAULT_ACCELERATION          3000    // X, Y, Z and E acceleration for printing moves
#define DEFAULT_RETRACT_ACCELERATION  3000    // E acceleration for retracts
#define DEFAULT_TRAVEL_ACCELERATION   3000    // X, Y, Z acceleration for travel (non printing) moves
#define DEFAULT_XJERK                 20.0
#define DEFAULT_YJERK                 20.0
#define DEFAULT_ZJERK                 10.0
#define DEFAULT_EJERK                  5.0
#define Z_MIN_PROBE_USES_Z_MIN_ENDSTOP_PIN
#define X_PROBE_OFFSET_FROM_EXTRUDER 10  // X offset: -left  +right  [of the nozzle]
#define Y_PROBE_OFFSET_FROM_EXTRUDER 10  // Y offset: -front +behind [the nozzle]
#define Z_PROBE_OFFSET_FROM_EXTRUDER 0   // Z offset: -below +above  [the nozzle]
#define XY_PROBE_SPEED 8000
#define Z_PROBE_SPEED_FAST HOMING_FEEDRATE_Z
#define Z_PROBE_SPEED_SLOW (Z_PROBE_SPEED_FAST / 2)
#define Z_CLEARANCE_DEPLOY_PROBE   10 // Z Clearance for Deploy/Stow
#define Z_CLEARANCE_BETWEEN_PROBES  5 // Z Clearance between probe points
#define Z_PROBE_OFFSET_RANGE_MIN -20
#define Z_PROBE_OFFSET_RANGE_MAX 20
#define X_ENABLE_ON 0
#define Y_ENABLE_ON 0
#define Z_ENABLE_ON 0
#define E_ENABLE_ON 0 // For all extruders
#define DISABLE_X false
#define DISABLE_Y false
#define DISABLE_Z false
#define DISABLE_E false // For all extruders
#define DISABLE_INACTIVE_EXTRUDER true // Keep only the active extruder enabled.
#define INVERT_X_DIR false
#define INVERT_Y_DIR true
#define INVERT_Z_DIR false //false
#define INVERT_E0_DIR true
#define INVERT_E1_DIR false
#define INVERT_E2_DIR false
#define X_HOME_DIR 1
#define Y_HOME_DIR 1
#define Z_HOME_DIR 1
#define X_BED_SIZE 200
#define Y_BED_SIZE 200
#define X_MIN_POS 0
#define Y_MIN_POS 0
#define Z_MIN_POS 0
#define X_MAX_POS 960
#define Y_MAX_POS 960
#define Z_MAX_POS 50//46
#define MIN_SOFTWARE_ENDSTOPS
  #define MIN_SOFTWARE_ENDSTOP_X
  #define MIN_SOFTWARE_ENDSTOP_Y
  #define MIN_SOFTWARE_ENDSTOP_Z
#define MAX_SOFTWARE_ENDSTOPS
  #define MAX_SOFTWARE_ENDSTOP_X
  #define MAX_SOFTWARE_ENDSTOP_Y
  #define MAX_SOFTWARE_ENDSTOP_Z
#define HOMING_FEEDRATE_XY (50*80)
#define HOMING_FEEDRATE_Z  (4*60)
#define EEPROM_SETTINGS // Enable for M500 and M501 commands
#define DISABLE_M503    // Saves ~2700 bytes of PROGMEM. Disable for release!
#define EEPROM_CHITCHAT   // Give feedback on EEPROM commands. Disable to save PROGMEM.
#define HOST_KEEPALIVE_FEATURE        // Disable this if your host doesn't like keepalive messages
#define DEFAULT_KEEPALIVE_INTERVAL 2  // Number of seconds between "busy" messages. Set with M113.
#define BUSY_WHILE_HEATING            // Some hosts require "busy" messages even during heating
#define PREHEAT_1_TEMP_HOTEND 180
#define PREHEAT_1_TEMP_BED     70
#define PREHEAT_1_FAN_SPEED     0 // Value from 0 to 255
#define PREHEAT_2_TEMP_HOTEND 240
#define PREHEAT_2_TEMP_BED    110
#define PREHEAT_2_FAN_SPEED     0 // Value from 0 to 255
#define PRINTJOB_TIMER_AUTOSTART
#define LCD_LANGUAGE en
#define DISPLAY_CHARSET_HD44780 JAPANESE
#define SDSUPPORT
#define REPRAP_DISCOUNT_FULL_GRAPHIC_SMART_CONTROLLER
#define SOFT_PWM_SCALE 0
#define SERVO_DELAY { 300 }

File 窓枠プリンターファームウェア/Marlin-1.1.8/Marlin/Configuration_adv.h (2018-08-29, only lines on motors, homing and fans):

#define E0_AUTO_FAN_PIN -1
#define E1_AUTO_FAN_PIN -1
#define E2_AUTO_FAN_PIN -1
#define E3_AUTO_FAN_PIN -1
#define E4_AUTO_FAN_PIN -1
#define X_DUAL_STEPPER_DRIVERS
#define X_HOME_BUMP_MM 5
#define Y_HOME_BUMP_MM 5
#define Z_HOME_BUMP_MM 2
#define HOMING_BUMP_DIVISOR { 2, 2, 4 }  // Re-Bump Speed Divisor (Divides the Homing Feedrate)
#define MICROSTEP_MODES {16,16,16,16,16} // [1,2,4,8,16]
#define DIGIPOT_I2C_MOTOR_CURRENTS { 1.0, 1.0, 1.0, 1.0, 1.0, 1.0, 1.0, 1.0 }  //  AZTEEG_X3_PRO

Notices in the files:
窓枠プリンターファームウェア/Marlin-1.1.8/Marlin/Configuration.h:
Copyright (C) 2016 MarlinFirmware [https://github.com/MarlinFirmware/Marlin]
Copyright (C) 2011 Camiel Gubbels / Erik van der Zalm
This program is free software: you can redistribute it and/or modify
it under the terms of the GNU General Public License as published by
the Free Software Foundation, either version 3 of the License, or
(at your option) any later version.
